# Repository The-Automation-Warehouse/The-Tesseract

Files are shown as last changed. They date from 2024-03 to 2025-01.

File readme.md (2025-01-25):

# The Tesseract

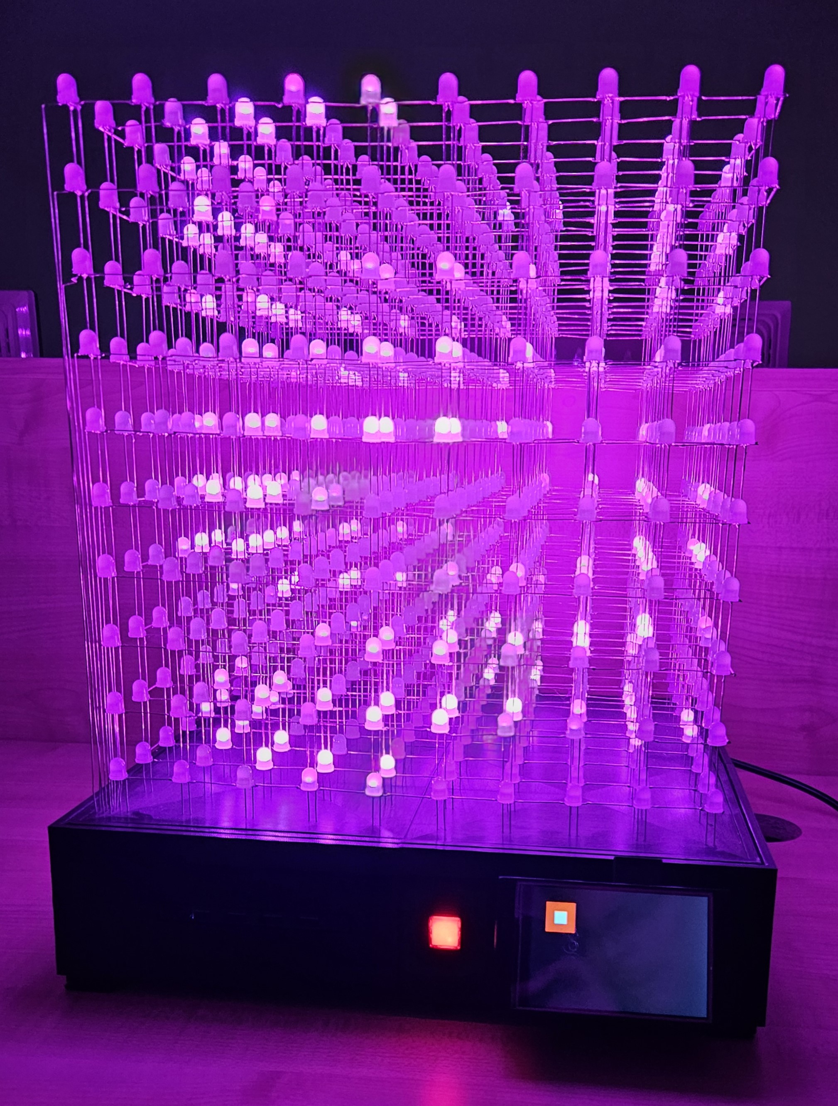
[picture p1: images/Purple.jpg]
Finished Project


## Introduction
This project is my DIY take on the popular RGB LED cube. I have always been fascinated by the mesmerizing patterns and animations that can be created with these cubes, so I used my school seminary work as an oporunity to build one myself and decided to turn in into a fully open-source project and guide for anyone who wants to build their own.

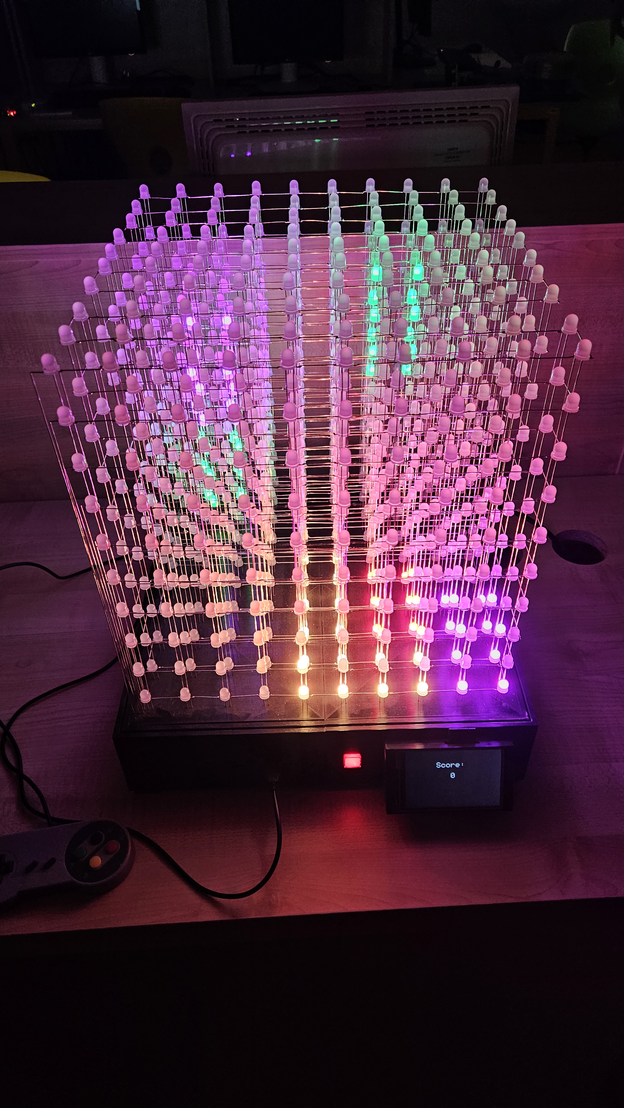
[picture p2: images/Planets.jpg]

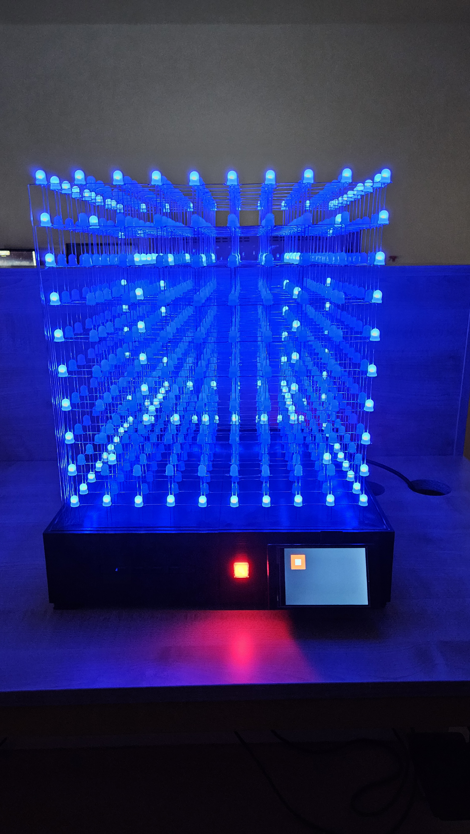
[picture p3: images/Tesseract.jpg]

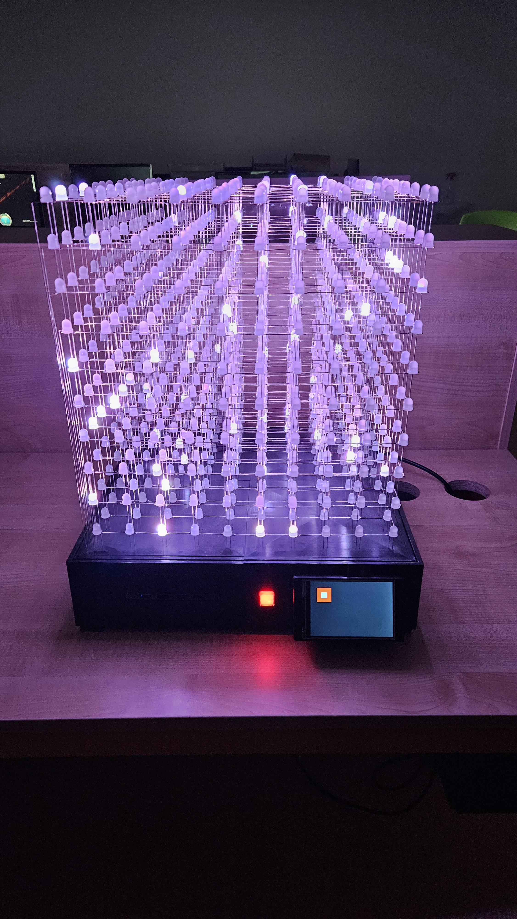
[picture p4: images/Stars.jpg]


## My Design
I decided to build a 10^3 cube, which means it has 1000 LEDs. I was thinking about making it bigger (12^3), but I wanted to keep the cost reasonable. In hindsight, if I had known how much time and effort it would take to build this cube, I would have gone for a much smaller one. But I am happy with the result, and I learned a lot in the process.<br>
I wanted the cube to be RGB and keep the electronics as simple as possible, so I used 8mm WS2812 LEDs, which are individually addressable and only need one data connection per LED stream.<br>
Most of the frame is make of custom PETG 3D printed parts, with some aluminum profiles and HDF board for structural support.<br>
For the brains of the cube, I used a teensy 4.1 microcontroller, which is a very powerful board that can handle the all of the LEDs and peripherals with ease.<br>
The user interface consists of a 4" TFT touch screen and a reset button (just in case).<br>
In the end the total cost was around 750 USD (720€), which is a lot, but I spent a lot of money on prototypes that ended up in the garbage, so I think it could be done for around 450 USD (430€) if you know what you are doing beforehand.

## Features
- 10 animations
- VU meter (audio reactive effect)
- TETRIS game via SNES controller
- Text rendering
- aprox. 300fps (effect dependent)

## How to build it

> [!TIP]
> - Refer to the CAD files and schematics, I tried to make them as detailed as possible.
> - Test the LEDs before soldering them, I know it is a pain (it took me 7 hours), but it is worth it.
> - Use the printed jigs (more on that later) to make the assembly easier.
> - **Turn off the power supply when working on the cube**, I know it is obvious, but I fried more than 30 LEDs after the cube was put together and resoldering them was a nightmare.
> - A good soldering iron helps a lot.

### Step 1: The LED structure :bulb:
The cube is split into walls and layers. Each wall has 100 LEDs, in 10 columns. Every wall is flipped 180º from the previous one. This results in a zig-zag pattern when viewed from the top. Every layer has its own data connection, to the MCU (more on that later). The walls are inserted into base plates and soldered together.

*Photo from the top here*
*Photo from the side here*

### Step 2: Preparing the wire
The LED connections are made with 0.8mm diameter silver copper wire. I got mine in 13m spools, and I ended up using 9 of them. The wire needs to be straightened and cut.<br>
Use a drill and a wise (or better a helper and pliers) to hold, pull and twist the wire (changing the direction every 8sec) until it is straight. Then use the cutting jig to cut the wire into 21mm pieces with wire cutters. For the collum power wires, cut 100 pieces of around 450mm (I used 500mm and it was too much, but I wanted to be safe).<br>

### Step 3: Soldering the LEDs
**Print the jigs**, soldering is practically impossible without them. 
There are 2 jigs (for the odd and even walls), each consisting of 4 parts that interlock like jig-saw puzzle. The 3d prints are not very heat resistant so I ended up melting them after 2-3 layers so I reprinted all of them 3 times to make the assembly easier.

Jig

Insert the LEDs into the jig in the right orientation, bend the outer legs to their respective sides and the inner two legs up.<br>
Cut the legs 2mm from the LED body and solder a connection wire to the outer legs between all of the LEDs. You should end up with 90 connections in total.<br>
Then solder the longer power wire to the inner legs, connecting all of the LEDs in the column. You should end up with 10 connections in total.<br>

Repeat this process 5 times for each jig, to end up with 10 walls.<br>

Wall
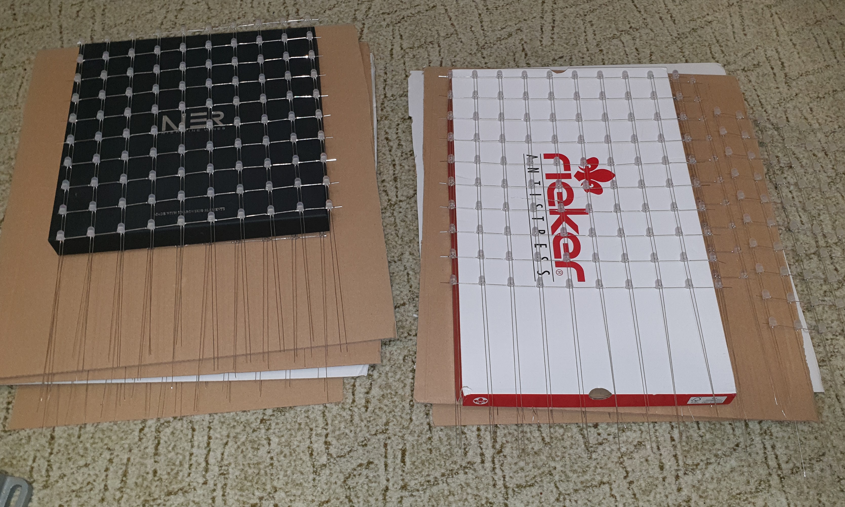
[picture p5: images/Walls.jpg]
Walls


*This looks quick and easy, but it took me around 3 months (working after school and on weekends) to finish all of the walls.*

### Step 4: Making the base plates
The base plates are made of two layers: a 3mm HDF board and a 3D printed grid. And they are split into 4 parts to make the manufacturing easier.

HDF base
Printed base

Cut 4 HDF boards to 175x175mm *drill holes for the LEDs*. The 4 plates are identical, but each is mirrored to the other. <br>
The drilling has to be precise, so I used a cheap 3018 CNC with a 1mm drill to make the HDF boards. You can find the excelon files in the CAD folder.<br>

Drilling

The 3D printed boards are just for looks and you can pain the HDF boards instead, but I think the 3D printed boards make the cube look more professional. I wasnt sure about the accuracy of the 3D printer for such small holes, so I made the holes Only on the bottom really small and drilled them on a drill press to the right size (0.8mm).<br>
I also picked a nice looking top infill pattern in the slicer to make the cube look better.

The front left plates need 10 holes in the front left corner for the data connections, I decided to make those by hand with a drill press, but you can also use the CNC for that.<br>

Printed base data

### Step 5: Connecting the walls to the base plates

This is definitely the most finicky part of the build. The walls have to be inserted into the base plates and soldered together. I used a very unstable rig to lower the walls into the base plates one by one (it ended ub collapsing and breaking a lot of solder joints, so I would recommend using something else).<br>

Rig

Insert the walls in an alternating pattern, checking the data flow. Start at the back with a wall that has the data connection going to the left, then insert a wall with the data connection going to the right, and so on. You should end up with a zig-zag pattern. Starting in the front left corner where the data input holes are.<br>
After the walls are inserted, the connections have to be soldered. Cut some more silver copper wire and solder the data connections to end of the walls.<br>

> [!TIP]
> - Print the brackets to hold the walls in place while soldering, it makes the process a lot easier. And reduces the risk of breaking the walls.

Cube structure

### Step 6: Wiring the base plates

You might have noticed that the polarity of the columns is a mess. This is to make the data connections easier and allow for more even current distribution.

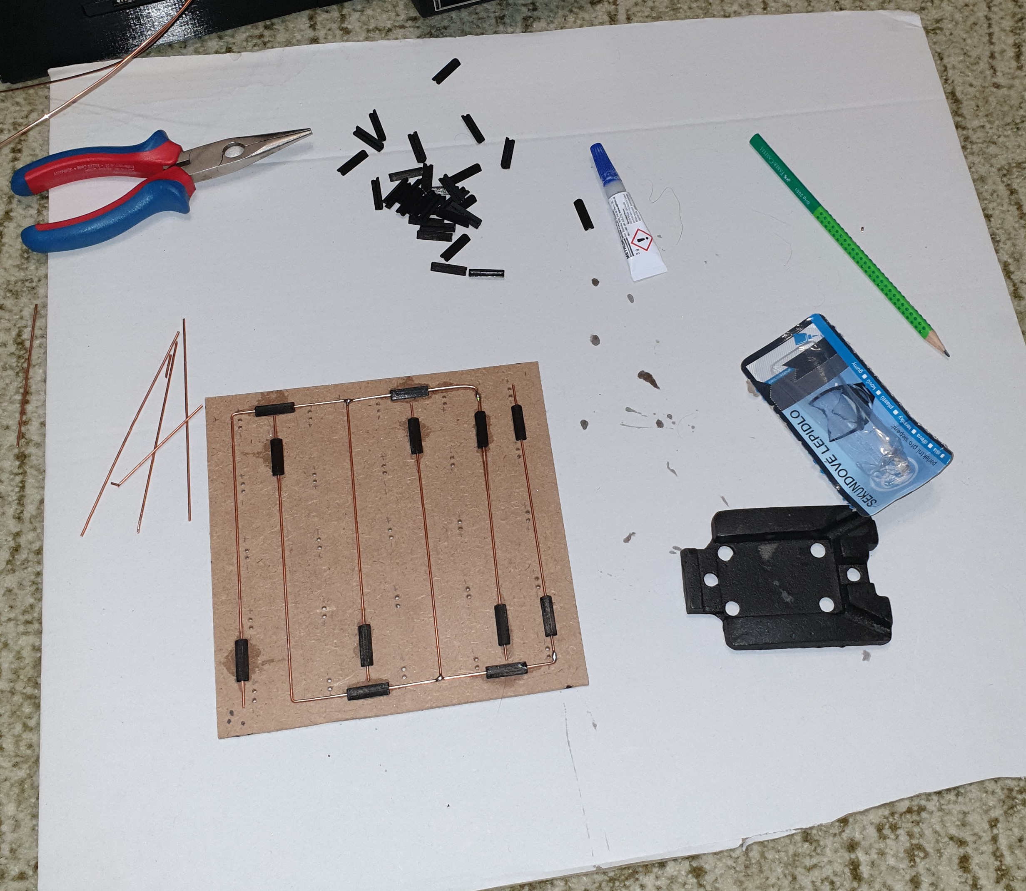
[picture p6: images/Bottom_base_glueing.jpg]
Bottom base glueing


I used 1.5mm2 wire and a lot of solder to make what I call the power planes. Each corner consists of two "power forks", one for +5V and one for GND. The silvered copper wire of each collum is directly soldered to the power planes.<br>

The thick wire is secured to the HDF with printed clamps and superglue (I would recommend using hotglue, because the superglue was very messy).<br>

> [!CAUTION]
> Pay attention to the polarity of the LEDs, flipping the power wires will burn the LEDs.

To connect the base plates to the PSUs, I used flexible 1.5mm2 wire and XT60 connectors soldered to the power planes. The other side of the XT60 connectors is soldered to the PSU wires.<br>
The data connections are made with thin ribbon cable, which is soldered to the 10 data connections on the front left corner of the base plates. The other side of the ribbon cable is connected to the motherboard with dupont connectors.<br>

Data cable
Bottom base wiring

### Step 7: Making the base frame

The frame is composed of 4 printed corners joined by 4 butterfly clips, 2 T aluminum profiles that hold the LED base plates and 5mm 350x350mm HDF board that everything is mounted on.

Corner Frame

Each corner has features and holes to mount specific peripherals (ex. the touch screen, the power inlet etc.).<br>
The remaining stuff is mounted on the HDF board with small wood screws - refer to the CAD files for the exact positions.<br>

Frame

### Step 8: The motherboard

The motherboard is a custom PCB that holds the Teensy 4.1, fusees, power distribution, battery clip, and all connectors for the peripherals.
I started by making a prototype on a breadboard and milling the next one on my CNC. The final version was made by JLCPCB, because it was too complex for me to make at home.

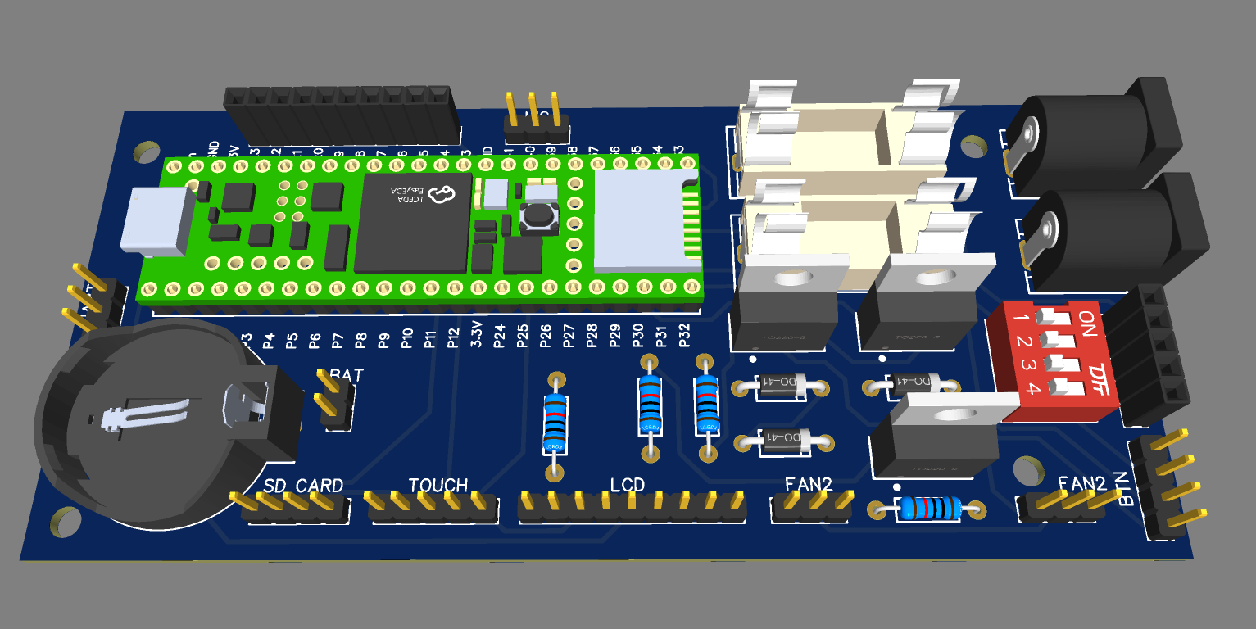
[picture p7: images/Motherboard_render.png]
Motherboard
 <br>

Breadboard
PCB prototype <br>

The board has DC jacks and fuses for 5V and 12V input (both required), a battery clip for the RTC, a port with DIP switches for a MAX9814 microphone breakout board, two MOSFET driven fan ports, breakout pins for the SPI touch screen with integrated SD card reader, and breakout pins for a reset button mounted in the front. There are also UART pins and analog MIC inputs, but I didn't use them in the final version.<br>
There are also dupont pins for the data connections to each layer of the cube.<br>
The most important part is the Teensy 4.1, which is the brains of the cube. It runs at 600MHz and has support for DMA which allows the cube to get up to 300fps in some animations.<br>

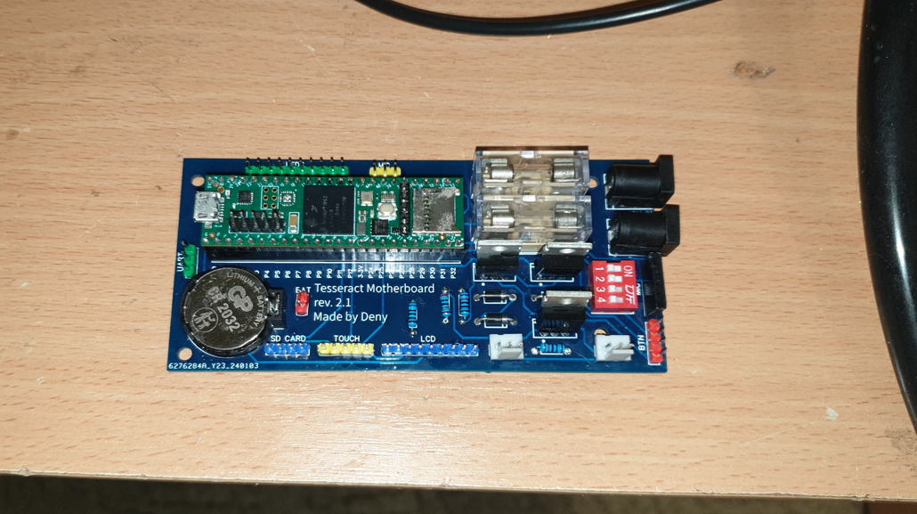
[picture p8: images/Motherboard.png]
Motherboard


### Step 9: Putting it all together :star:

If you have made it this far, congratulations:star2:! You are almost done. Now you just have to put everything without breaking it.<br>

Start by mounting all of the peripherals to the base frame.
- 2x 5V 40A PSU
- 12V 2A PSU
- The touch screen
- The reset button
- The USB hub
- 2x 12V fan
- C13 power inlet
- Back went cover
- Back IO (optional and not recommended)

Frame

Plug in all wires and place the LED structure on top of the base frame. Upload a test pattern and watch your cube come to life.

//video here

### Step 10: Software :computer:

The firmware is written in C++ and uses the FastLED library with the OctoWS2811 library to control the LEDs. The animations are stored in a separate file and are called by the main loop.<br>
The touch screen is controlled by the TFT_eSPI library and the touch screen library. The touch screen is mainly used to select animations. The SNES controller is connected via the USB hub and is used to play TETRIS.<br>

There is also a presentation mode, cycles through all of the animations.<br>

If you want to add your own animations, you can do so by adding a new function to the animations file and calling it in the main loop.

### Step 11: Enjoy you new RGB LED cube :tada:

I hope you enjoyed building this cube as much as I did. I learned a lot and I am very happy with the result. I hope you are too. If you have any questions or suggestions, feel free to post an issue or contact me directly.

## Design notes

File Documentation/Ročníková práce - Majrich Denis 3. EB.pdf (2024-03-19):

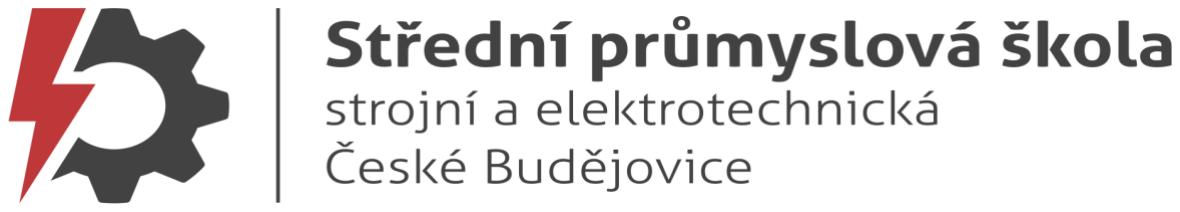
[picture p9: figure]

1

# The TESSERACT – Trojrozměrný LED displej ve tvaru krychle

## Ročníková práce

Jméno a příjmení: Denis Majrich | Třída: 3. EA

Vedoucí ročníkové práce: Ing. Lubomír Krejsa

Předmět: Mikroprocesorová technika

Školní rok: | 2023 – 2024

Střední průmyslová škola strojní a elektrotechnická České Budějovice, Dukelská 13

## Zadání ročníkové odborné práce

2

Zadání je vystaveno pro studenta :

Jména a příjmení: | Denis Majrich
Datum narození: | 2. 5. 2006
Třída: | 3. EA

Téma ročníkové práce:

### Trojrozměrný LED displej ve tvaru krychle

Požadované dílčí body práce:

1. Cílem ročníkové práce je vytvořit LED displej složený z jednoho tisíce jednotlivě

programovatelných LED diod uspořádaných do tvaru kostky o velikosti 10 x 10 x 10 diod.

2. Pro řízení displeje je nutné z důvodu vysokého výpočetního výkonu využít mikrokontroler

TEENSY 4.1.

3. K interakci s uživatelem bude sloužit dotykový TFT LCD displej s rozlišením 480 x 320 pixelů a

úhlopříčkou 4“.
4. Řídící software bude napsán v programovacím jazyce C++.

Cíl ročníkové odborné práce:

Prověřit znalosti studentů získané po dobu studia z odborných předmětů (elektronika, mikroprocesorová technika a IT) návrhem praktického zařízení.

Rozsah práce:

Práce bude obsahovat textovou část, která bude doplněná stručnou charakteristikou řešené problematiky, potřebnými náčrtky, schématy a tabulkami, vše v rozsahu minimálně 4 strany strojně psaného textu. Výkresová dokumentace bude obsahovat schéma zapojení, či jiná schémata potřebná k pochopení práce. Celá práce bude obsahovat obsah, přehled použitých značek s jejich názvem a jednotkami a zdroje. Práce se odevzdává ve dvou výtiscích – jedno pro vedoucího práce, druhý zůstává v archivu školy. Oba výtisky předá student vedoucímu práce.

3

Konzultace:

Student může po dobu zpracování ročníkové práce zkonzultovat výsledky doposud zpracované práce s vedoucím práce. Poslední konzultace je však nejpozději čtrnáct dní před odevzdáním.

Termín odevzdání práce: | 29.2.2024
Vedoucí práce: | Ing. Lubomír Krejsa | |
| | Podpis
Předseda předmětové komise: Ing. Lubomír Krejsa | |
| | Podpis
Kritéria hodnocení: | Hodnocení provádí vedoucí práce. Hodnotí se kvalita vypracování
dokumentace, správnost výpočtů a funkčnost navrženého zařízení.
Výsledné hodnocení: | výborný
| chvalitebný
| dobrý
| dostatečný
| nedostatečný

V Českých Budějovicích 03.10.2023

Převzetí zadání dlouhodobé ročníkové práce

Dne: | | | Podpis studenta

4

### Obsah

### 1. ÚVOD | 5

### 2. POSTUP PRÁCE | 6

2.1 | KONSTRUKCE | 6
2.1.1 | CAD | 6
2.1.2 | Podstava | 6
2.1.3 | Nosné desky | 7
2.1.4 | Uchycení displeje | 7
2.1.5 | LED diody | 8
2.2 | ŘÍDÍCÍ ELEKTRONIKA | 9
2.2.1 | Napájení | 9
2.2.2 | Řízení krychle a periferií | 9
2.2.3 | Systém Home Assistant | 10
2.3 | THE OMNITOUCH | 10
2.4 | SOFTWARE | 11
2.4.1 | Teensy 4.1 | 11
2.4.2 | Home Assistant | 12
2.4.3 | The Omnitouch | 12

### 3. ZÁVĚR | 14

SEZNAM ZKRATEK | 15
ZDROJE | 16
SEZNAM PŘÍLOH | 188

5

## 1. Úvod

Cílem mé ročníkové práce je vytvořit LED displej složený z jednoho tisíce jednotlivě programovatelných LED diod uspořádaných do tvaru kostky o velikosti 10 x 10 x 10 diod. Pro řízení displeje plánuji z důvodu nutnosti vysokého výpočetního výkonu využít mikrokontroler TEENSY 4.1. K interakci s uživatelem bude sloužit dotykový TFT LCD displej s rozlišením 480 x 320 pixelů a úhlopříčkou 4″.
Řídící software bude napsán v programovacím jazyce C++.
S použitím zvukového senzoru by animace na displeji mohly reagovat na okolní zvuky a hudbu.
Rád bych do projektu zakomponoval dva SNES ovladače s USB rozhraním, které umožní hrát na kostce různé hry pro jednoho nebo dva hráče jako např. PONG a do budoucna např. i TETRIS.
Dotykový displej bude obsahovat dvě různá menu, z nichž první bude určeno pro přehrávání animací nebo statických obrázků, druhé menu bude sloužit k volbě obtížnosti, počtu hráčů a zahájení her.

6

## 2. Postup práce

Veškeré tištěné díly jsou vytvořeny v programu Autodesk Fusion 360 a vytištěny na 3D tiskárně Prusa i3 Mk3S+ (viz příloha Modely) z černého materiálu PLA. Schémata zapojení a DPS jsou vytvořena v programu EasyEDA (viz příloha PCBs).

## 2.1 Konstrukce

### 2.1.1 CAD

Prvním krokem mé práce bylo sestavení požadavků na design mechanické konstrukce projektu.
Pro vytvoření modelu jsem využil software Autodesk Fusion 360, ve kterém jsem vymodeloval prototyp nosné konstrukce, u kterého jsem si určil rozteč jednotlivých diod a propočítal velikost finální krychle a její podstavy. Na základě toho jsem zjistil, kolik vznikne v podstavě prostoru na napájení, řídící elektroniku a kabeláž.

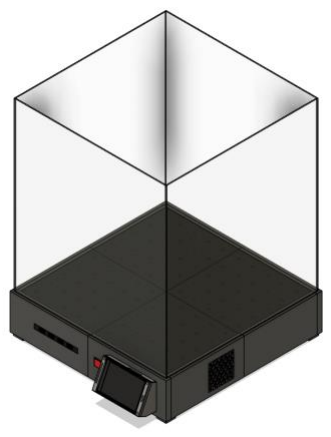
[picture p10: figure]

### 2.1.2 Podstava

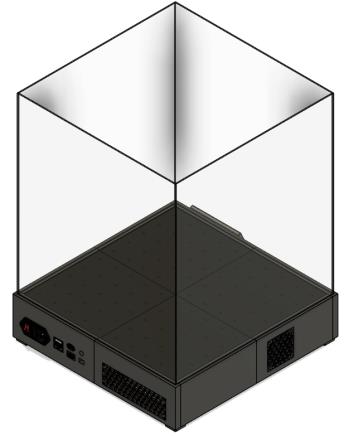
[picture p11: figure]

Výsledné rozměry podstavy jsou 375 x 375 mm, proto jsem se rozhodl rozdělit ji na čtyři části, které jsem poté spojil rybinovými ozuby, díky čemuž bylo možné je vytisknout na 3D tiskárně.

Spodní část podstavy tvoří sololitová deska natřená šedou barvou o tloušťce 4 mm z důvodu nutnosti udržení veškeré elektroniky.

Vrchní část je vyztužena dvěma na sebe kolmými hliníkovými profily ve tvaru T za účelem jejího osazení osmi nosnými deskami pro LED diody.

Do stran podstavy jsou vymodelovány otvory o různých rozměrech a tvarech, do kterých jsou zasazeny vstupní a výstupní periferie (např. chladící ventilátory, USB hub, hlavní vypínač, přívodní konektor nebo ethernet port).

Podstava má v každém rohu umístěnou nohu s pěnovým čtvercem z důvodu ochrany stolu.

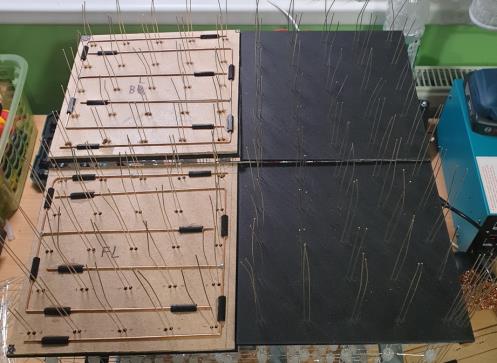
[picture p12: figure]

7

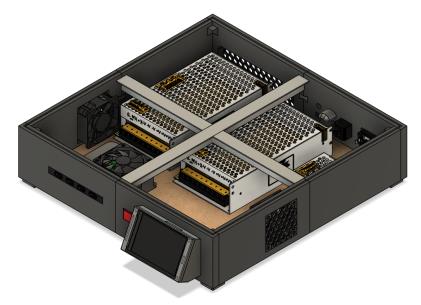
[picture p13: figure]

### 2.1.3 Nosné desky

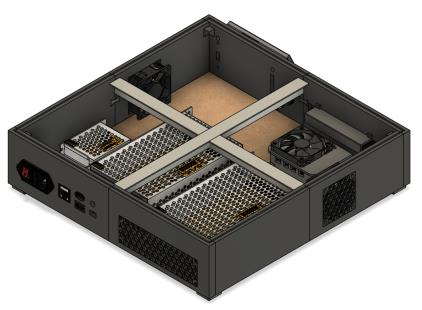
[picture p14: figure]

Konstrukce LED diod je osazena na osmi nosných deskách o rozměrech 175 x 175 x 3 mm s přesně určenými dírami pro lepší stabilitu.

Vrchní čtyři desky jsou vytištěny ze stejného materiálu jako podstava s koncentrickou vrchní výplní a slouží pouze pro zakrytí spodních čtyř desek ze 3 mm tlustého sololitu, na které jsou připevněné napájecí rozvody. Díry jsou vymodelované pouze do poloviny vrchních desek, kdy následně každá z nich představuje předlohu pro ruční vrtání spodní desky ze sololitu.

V levé přední desce se v levém předním rohu nachází deset těsně u sebe vyvrtaných děr pro protažení datových rozvodů jednotlivých vrstev krychle.

### 2.1.4 Uchycení displeje

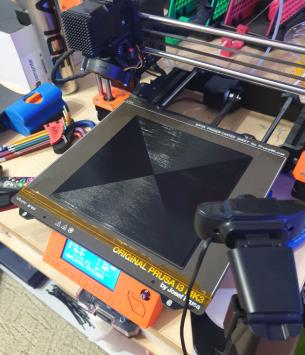
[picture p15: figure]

4″ TFT LCD displej je na pravé přední straně podstavy uchycen pod úhlem 25o tak, aby při pohledu na displej nebyly nikde patrné uchycovací šrouby a zároveň byl přístupný slot na SD kartu v horní části displeje.

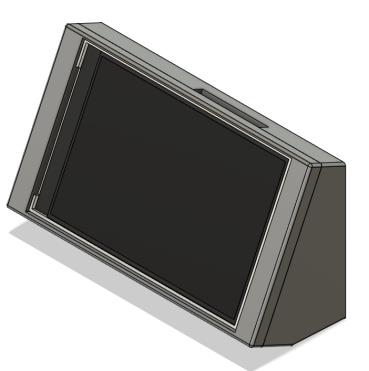
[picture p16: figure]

8

### 2.1.5 LED diody

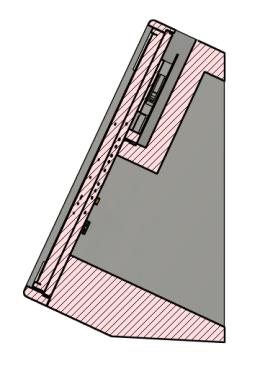
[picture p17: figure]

Krychle se skládá z jednoho tisíce adresovatelných RGB LED diod (pixelů) se zabudovaným ic WS28111, jenž umožňuje diody řídit 12 bity pro každou diodu; tedy celkem 2553 barev pro každý pixel.

Deset diod v každém ze sta sloupců je vertikálně připevněno na dvou měděných postříbřených drátech o průměru 0,8 mm.

Dráty zajišťují napájení každé diody v paralelním zapojení (viz bod 2.2.1).

Jednotlivé sloupce diod jsou spojeny v každé vrstvě stejným postříbřeným drátem. Stěny jsou mezi sebou propojovány drátem vždy střídavě ob jeden sloupec.

V levém předním rohu se nachází 10 datových vodičů, díky kterým lze řídit každou vrstvu nezávisle na ostatních devíti.

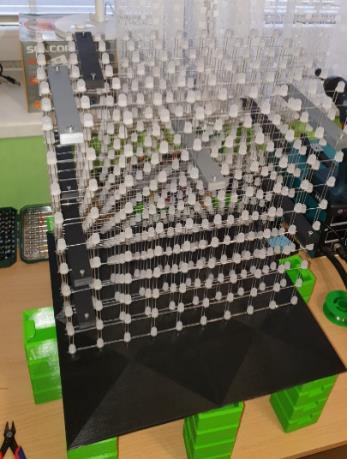
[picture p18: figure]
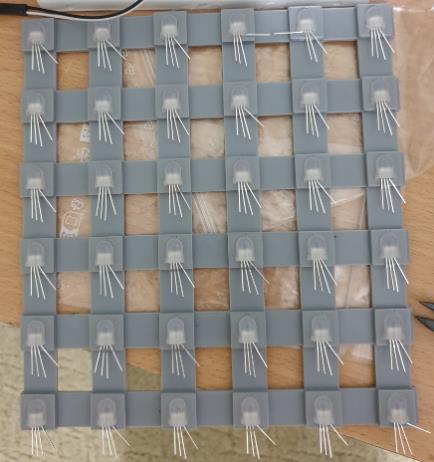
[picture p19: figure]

Pro usnadnění pájení jednotlivých vrstev jsem si vymodeloval a vytiskl plastové přípravky.

_____________________________

1
Stránky prodejce diod s dokumentací [online]. [cit. 12.2.2024]. Dostupné z: https://www.aliexpress.com/item/4000720415203.html?spm=a2g0o.order_list.order_list_main.9.76 c81802TY4kjk (https://www.aliexpress.com/item/4000720415203.html)

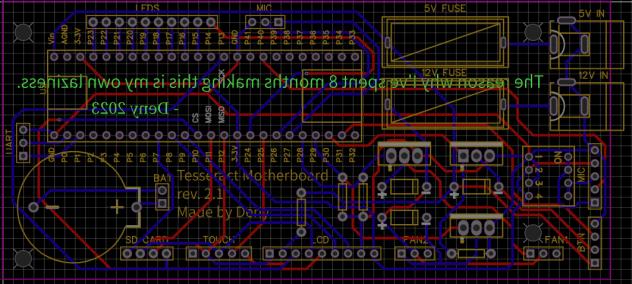
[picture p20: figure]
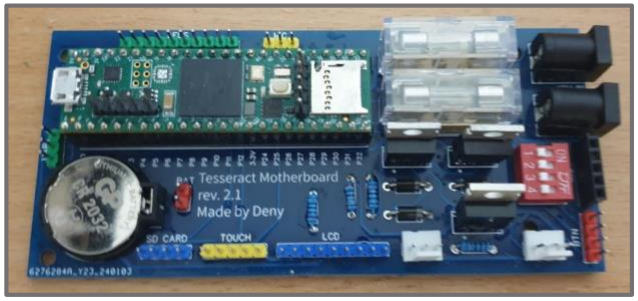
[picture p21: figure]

9

## 2.2 Řídící elektronika

### 2.2.1 Napájení

Napájení celého projektu zajišťují tři zdroje, z toho dva s nominálním napětím 5V a maximálním proudem 40A a třetí s nominálním napětím 12V a maximálním proudem 2A.

5V zdroje slouží k napájení diod a veškeré řídící elektroniky. 12V zdroj je určen pro dva chladící ventilátory umístěné po bocích podstavy.

Distribuce proudu LED diod je realizována paralelním spojením všech pixelů na spodní části nosných desek. Jednotlivé kvadranty jsou se sloupci spojené měděným drátem o průřezu 1,5 mm a k příslušnému napájecímu zdroji jsou připojeny lankovým vodičem o průřezu 2,5 mm. Toto spojení minimalizuje úbytek napětí mezi diodami.

### 2.2.2 Řízení krychle a periferií

Pro snadnější zapojení řídící elektroniky jsem se rozhodl navrhnout vlastní DPS, která umožní snadné propojení řídícího mikrokontroleru, vrstev krychle a veškerých periferií.

První verzi DPS jsem vyrobil pomocí CNC frézy, po zjištění a opravě veškerých nedostatků jsem finální verzi DPS objednal od externího dodavatele.

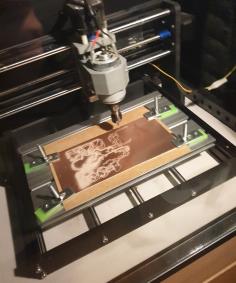
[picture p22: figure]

Jako hlavní mikrokontroler jsem zvolil TEENSY 4.1, a to např. kvůli jeho vysoké pracovní frekvenci až 1,08 GHz, paměti Flash o velikosti 8 MB, paměti RAM o velikosti 1024 kB, 55 vstupně/výstupním pinům, matematickému koprocesoru a užitečné funkci DMA, která umožňuje řídit všechny vrstvy krychle najednou a dosáhnout tak obnovovací frekvence ca 320 fps.

Mikrokontroler dále řídí také přes sběrnici SPI:

10

4″ TFT LCD displej

dotykovou vrstvu displeje

slot na SD kartu

Funkce USB host zajišťuje komunikaci mezi zařízeními USB připojenými přes hub v přední části podstavy a jeho primární využití je pro dva SNES ovladače určené pro hraní her, např. TETRIS nebo PONG (prozatím pro jednoho hráče; v budoucnu plánuji přidat režim pro více hráčů).

Pomocí dvou unipolárních tranzistorů typu MOS s N-kanálem jsou ovládány dva chladící ventilátory s možností regulace výkonu prostřednictvím PWM.

Tlačítko se zabudovaným podsvícením se stejnou regulací jako ventilátory slouží pro nouzové vypnutí a reset mikrokontroleru.

Některé světelné efekty mohou reagovat na okolní zvuk (hudbu) ze dvou zdrojů:

mikrofon MAX9814 se zabudovaným zesilovačem s nastavitelným zesílením pomocí DIP přepínačů na DPS

dvoukanálový audiojack s RC filtrem připojený do Raspberry Pi 4 (viz bod 2.2.3)

Mikrokontroler je propojen s Raspberry Pi 4 (viz bod 2.2.3) přes sériovou linku typu UART.

DPS obsahuje slot na baterii CR2032, která slouží k záložnímu napájení interních hodin reálného času uvnitř mikrokontroleru v případě výpadku hlavního zdroje.

### 2.2.3 Systém Home Assistant

V podstavě krychle je umístěn jednodeskový počítač Raspberry Pi 4B určený pro běh systému Home Assistant na ovládání chytré domácnosti. Tento systém umožňuje propojení zařízení pro chytrou domácnost od různých výrobců a jejich následnou integraci do vlastních programů, skriptů a automatizací.

Systém komunikuje s TEENSY 4.1 pomocí skriptu v jazyce Python přes protokol UART, přičemž posílá data o entitách v systému a příkazy z ovladače The Omnitouch (viz bod 2.3). Tím je zajištěna interakce mezi zařízeními chytré domácnosti (např. světly, zásuvkami, počítači, senzory atd.) a krychlí TESSERACT.

Do projektu plánuji zahrnout vizualizaci hlasového asistenta na krychli.

## 2.3 The Omnitouch

Pro názornou ukázku univerzálnosti platformy Home Assistent jsem vytvořil zařízení, které lze přes tuto platformu s krychlí propojit, a tím je The Omnitouch.

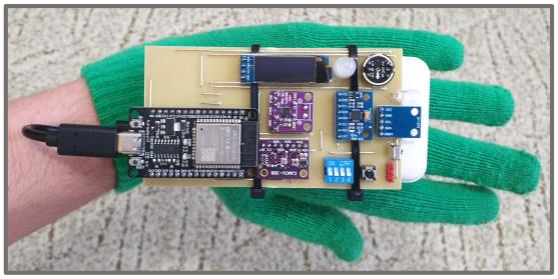
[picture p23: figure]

11

Jedná se o „rukavici“ s osmi senzory a čtyřmi přepínači, tlačítkem, RGB diodou, OLED displejem o rozlišení 128 x 32 pixelů a připojením prostřednictvím wifi skrze platformu a protokol ESPHome.

Základem je mnou navržená a vyrobená DPS s vývojovou deskou ESP32-WROOM-32D. Napájení přes konektor USB-C na vývojové desce zajišťuje powerbanka umístěná pod DPS.

Jednotlivé senzory The Omnitouch:

tříosý magnetometr a kompas HMC5883L

šestiosý akcelerometr MPU6050

detektor teploty a tlaku BMP388

Hallův senzor magnetického pole

mikrofon INNP441

IR přijímač VS1838B

Primární využití zařízení je při prezentaci krychle pro bezdrátové přepínání mezi efekty, vizualizaci teploty nebo magnetického pole.

I2S mikrofon slouží pro možnost hlasového ovládání chytré domácnosti.

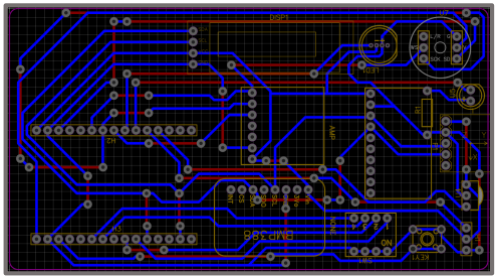
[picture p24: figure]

## 2.4 Software

### 2.4.1 Teensy 4.1

Řídící software pro mikrokontroler Teensy 4.1 je napsán v jazyce C++ pomocí deseti volně dostupných knihoven. Skládá se z hlavního skriptu main.cpp a pomocných souborů typu .h pro jednotlivé efekty a podřízené funkce.

Hlavní funkcí pro řízení diod je funkce void setLed(int x, int y, int z, CRGB color), jež je určena k nastavení jednoho pixelu krychle na určitou barvu. Jejím vstupem jsou kartézské souřadnice [x, y, z] následně převedené na index diody ve virtuálním poli pomocí funkce int getLedIndex(int x, int y, int z), kam funkce ukládá barevná data příslušné diody.

Celý kód mikrokontroleru je složen z přibližně 5000 řádek rozdělených do 22 souborů.

Jednotlivé soubory obsahují proměnné a funkce pro řízení částí a činností krychle, např.:

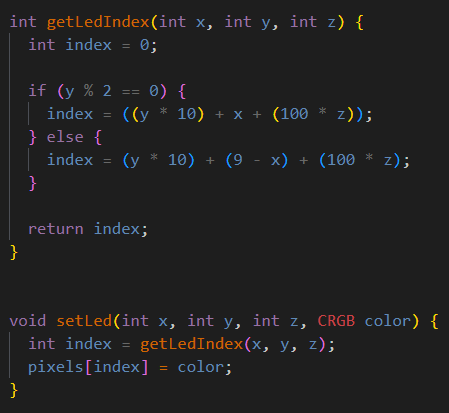
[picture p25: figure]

12

soubor pro řízení a zpracování dat SNES ovladačů

soubor pro virtuální mikrokontroler k řízení všech 10 vrstev krychle najednou pomocí DMA

soubor pro hraní hry TETRIS

soubor pro zpracování a vykreslování textu

soubor pro zpracování zvuku (hudby) a jeho převedení na frekvenční spektra za použití Fourierovy transformace a následné zobrazení jednotlivých pásem na krychli

pomocný soubor s funkcemi pro řízení SD karty, ladícími funkcemi nebo např. funkcí pro vykreslování virtuálních desetinných pixelů

soubor pro vykreslování hlavního menu, různých podmenu na LCD displeji, zpracování a filtraci dat z dotykové vrstvy

14 souborů týkajících se jednotlivých efektů LED diod

### 2.4.2 Home Assistant

Většina konfigurace systému Home Assistent probíhá ve vizuálním prostředí.

Pro pokročilejší funkce lze využít programovacího jazyka YAML. Dále lze pomocí rozšíření pyskript vytvářet a spouštět v pozadí systému podprogramy v jazyce Python, např. pro sériovou komunikaci s krychlí prostřednitvím UART.

### 2.4.3 The Omnitouch

Software pro The Omnitouch je vytvořen pomocí platformy ESPHome v programovacím jazyce YAML. Tato platforma umožňuje snadné propojení několika periferií skrze jednoduchou deklaraci jejich typů a atributů.

Pokročilejší funkce lze naprogramovat pomocí funkcí typu lambda.

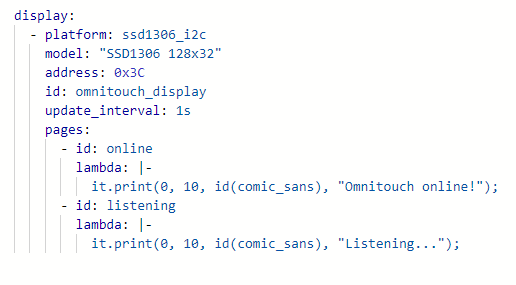
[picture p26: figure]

13

V přiložené složce Foto a video se nachází videa a fotografie práce.

14

## 3. Závěr

V souladu s cílem práce se podařilo vytvořit LED krychli s 1000 pixely s deseti funkčními efekty, z toho dvěma reagujícími na hudbu.

Základním efektem je duha, při které je vyplněna celá krychle jednou barvou, jež se vždy
v čase mění. Mezi další efekty patří např. vykreslování textu či hodin, náhodné hvězdy v bílé nebo barevné variantě, planety obíhající kolem středu nebo dvojitá spirála otáčející se kolem vertikální osy.

Na krychli je možné hrát známou hru TETRIS ve 3D pro jednoho hráče pomocí USB SNES ovladače (do budoucna plánuji rozšíření pro více hráčů).

Celá krychle obsahuje zabudovaný funkční systém Home Assistant pro řízení a automatizaci chytré domácnosti.

Efekty na krychli je možné např. pro účely prezentace přepínat pomocí chytré rukavice The Omnitouch, prostřednictvím níž lze také hlasově řídit chytrou domácnost.

Nejsložitější částí práce byl návrh a následná stavba konstrukce všech diod zejména z důvodu rozměrů krychle, a tudíž nestability tenkých měděných drátů. Často docházelo k přetržení pájených spojů nebo dokonce zničení některých diod.

Odhad celkových finančních nákladů na vytvoření LED krychle této ročníkové práce se pohybuje kolem 17 tis. Kč. Práce byla zhotovena v období 8 měsíců, největší časový prostor zabral CAD a pájení diod.

Hlavním přínosem zpracování projektu pro mne bylo zlepšení dovednosti pájení, programování v různých jazycích, modelování v CADu a návrh elektronických schémat a DPS.

Rozhodl jsem se celý projekt vč. softwaru, CADU ve formátu .step, fotografií a dokumentace zveřejnit na platformě GitHub pod licencí typu MIT (https://github.com/The-Automation-Warehouse/The-Tesseract.git) (https://github.com/The-Automation-Warehouse/The-Tesseract.git)

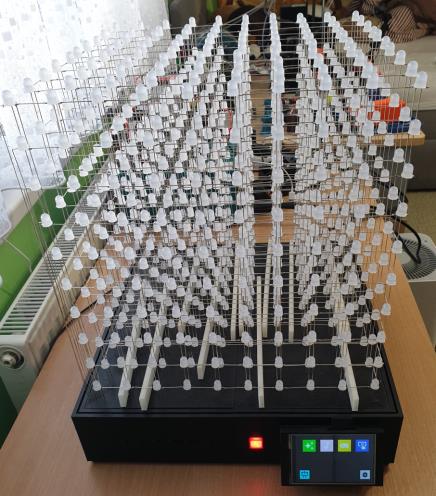
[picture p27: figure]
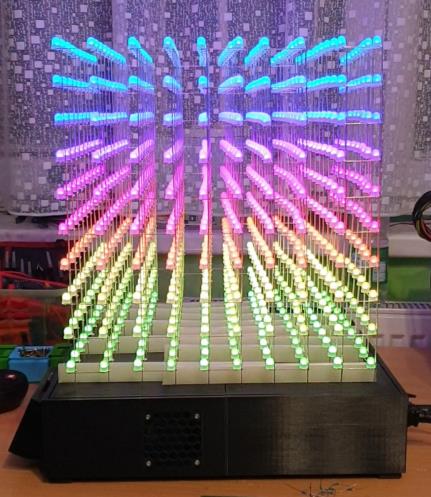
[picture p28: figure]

15

## Seznam Zkratek

TFT | Thin-film transistor (tenkovrstvé tranzistory)
LCD | Liquid crystal display (Displej z tekutých krystalů)
PLA | Polylactic acid (materiál pro 3D tisk)
CAD | Computed aided design (počítačem podporované projektování)
ic | Integrated circuit (zabudovaný čip)
DPS (PCB) | Printed circuit board (deska plošného spoje)
CNC | Computer numeric control (počítačové numerické řízení)
RAM | Random access memory (paměť s náhodným přístupem)
DMA | Direct memory access (přímý přístup k paměti)
fps | Frames per second (snímky za vteřinu)
SNES | Super nintendo entertainment system (herní platforma)
MOS | Metal oxide semiconductor (tranzistor řízený polem)
PWM | Pulse width modulation (pulzně šířková modulace)
DIP | Dual in-line package (pouzdro integrovaných obvodů)
UART | Universal asynchronous receiver-transmitter (typ počítačové sběrnice)
OLED | Organic light-emitting diode (technologie displeje)
I2S | Inter-IC Sound (typ počítačové sběrnice)

16

## Zdroje

### Internetové zdroje

1.Web prodejce LED diod s dokumentací [online]. Aliexpress. (2024). [cit. 12.2.2024]. Dostupné z:
https://www.aliexpress.com/item/4000720415203.html?spm=a2g0o.order_list.order_list_mai n.9.76c81802TY4kjk (https://www.aliexpress.com/item/4000720415203.html)
2. Web výrobce mikrokontroleru Teensy 4.1 s dokumentací [online]. 2024 PJRC. [cit. 12.12.2024]. Dostupné z: https://www.pjrc.com/store/teensy41.html
3. Web výrobce jednodeskového počítače Raspberry Pi 4B s dokumentací [online]. 2024 Raspberry Pi. [cit. 12.12.2024]. Dostupné z: https://www.raspberrypi.com/products/raspberrypi-4-model-b/ (https://www.raspberrypi.com/products/raspberry-pi-4-model-b/)
4. 3D model Raspberry Pi 4B [online]. 2024 Stratasys Inc. Grabcad.com. [cit. 12.12.2024]. Dostupné z: https://grabcad.com/library/raspberry-pi-4-model-b-5
5. 3D model Chladícího ventilátoru [online]. 2024 Stratasys Inc. Grabcad.com. [cit. 12.12.2024]. Dostupné z: https://grabcad.com/library/60-x-60-x-25-exhaust-fan
6. 3D model 12V zdroje [online]. 2024 Stratasys Inc. Grabcad.com. [cit. 12.12.2024]. Dostupné z: https://grabcad.com/library/fuente-conmutada-12v-2a-12v-3a-12v-5a-12v-10a-12v-30a-12v-50a-1 (https://grabcad.com/library/fuente-conmutada-12v-2a-12v-3a-12v-5a-12v-10a-12v-30a-12v-50a-1)
7. 3D model 5V zdroje [online]. 2024 Stratasys Inc. Grabcad.com. [cit. 12.12.2024]. Dostupné z: https://grabcad.com/library/fuente-conmutada-5v-3a-5v-10a-5v-40a-1
8. 3D model napájecího konektoru [online]. 2024 Stratasys Inc. Grabcad.com. [cit. 12.12.2024]. Dostupné z: https://grabcad.com/library/ac-power-socket-3-pin-250v-10a-ac-17-iec3-c14-1 (https://grabcad.com/library/ac-power-socket-3-pin-250v-10a-ac-17-iec3-c14-1)
9. 3D model konektoru RJ45 [online]. 2024 Stratasys Inc. Grabcad.com. [cit. 12.12.2024]. Dostupné z: https://grabcad.com/library/rj45-panel-mount-1
10. 3D model mikrokontroleru Teensy 4.1 [online]. 2024 Stratasys Inc. Grabcad.com. [cit. 12.12.2024]. Dostupné z: https://grabcad.com/library/teensy-4-1-3
11. 3D model vypínače [online]. 2024 Dassault Systèmes. 3dcontentcentral.com. [cit. 12.12.2024]. Dostupné z: https://www.3dcontentcentral.com/download-model.aspx?catalogid=171&id=345299 (https://www.3dcontentcentral.com/download-model.aspx?catalogid=171&id=345299)
12. 3D model 5V ventilátoru [online]. 2024 CUI Devices. Cuidevices.com. [cit. 12.12.2024]. Dostupné z: https://www.cuidevices.com/product/resource/3dmodel/cfm-6010v-130-205-20
13. 3D model USB portu [online]. 2024 CUI Devices. Cuidevices.com. [cit. 12.12.2024]. Dostupné z: https://www.cuidevices.com/product/resource/3dmodel/uj3-ah-4-th

17

Počítačové programy

1. Autodesk Inc, Fusion 360 [software]. 24. 9. 2013. Dostupné z: https://www.autodesk.cz/products/fusion-360.
2. Prusa Research a.s., Prusaslicer 2.5 [software]. 19. 8. 2022. Dostupné z: https://www.prusa3d.com/cs/stranka/prusaslicer_424/.
3. Microsoft corp, Visual Studio Code [software]. 29. 4. 2015. Dostupné z: https://code.visualstudio.com/.
4. PlatformIO Labs, PlatfromIO [software]. 6. 1. 2015 Dostupné z: https://platformio.org/.
5. LCSC, EasyEDA [software]. 14. 9. 2021. Dostupné z: https://easyeda.com/.
6. Nabu Casa, Home Assistant [software]. 19. 10. 2017 Dostupné z: https://www.home-assistant.io/. (https://www.home-assistant.io/)
7. Nabu Casa, ESPHome [software]. 7. 12. 2023 Dostupné z: https://esphome.io/index.html

18

## Seznam příloh

Příloha I. – elektronická složka Foto a video (videa různých efektů; videa o tisku dílů; video o zkoušce diod; 83 fotografií)

Příloha II. – elektronická složka Code (kód krychle – The Tesseract; kód ovladače Omnitouch – The Omnitouch)

Příloha III. – elektronická složka PCB (elektronická schémata v formátu .png a .json; soubory DPS ve formátu .png a gerber)

Příloha IV. – elektronická složka Modely (vlastní modely ve formátech .3mf, .step a .f3d)

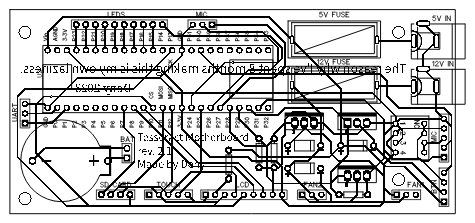
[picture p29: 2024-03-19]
PCB/Tesseract_Motherboard_PCB.png

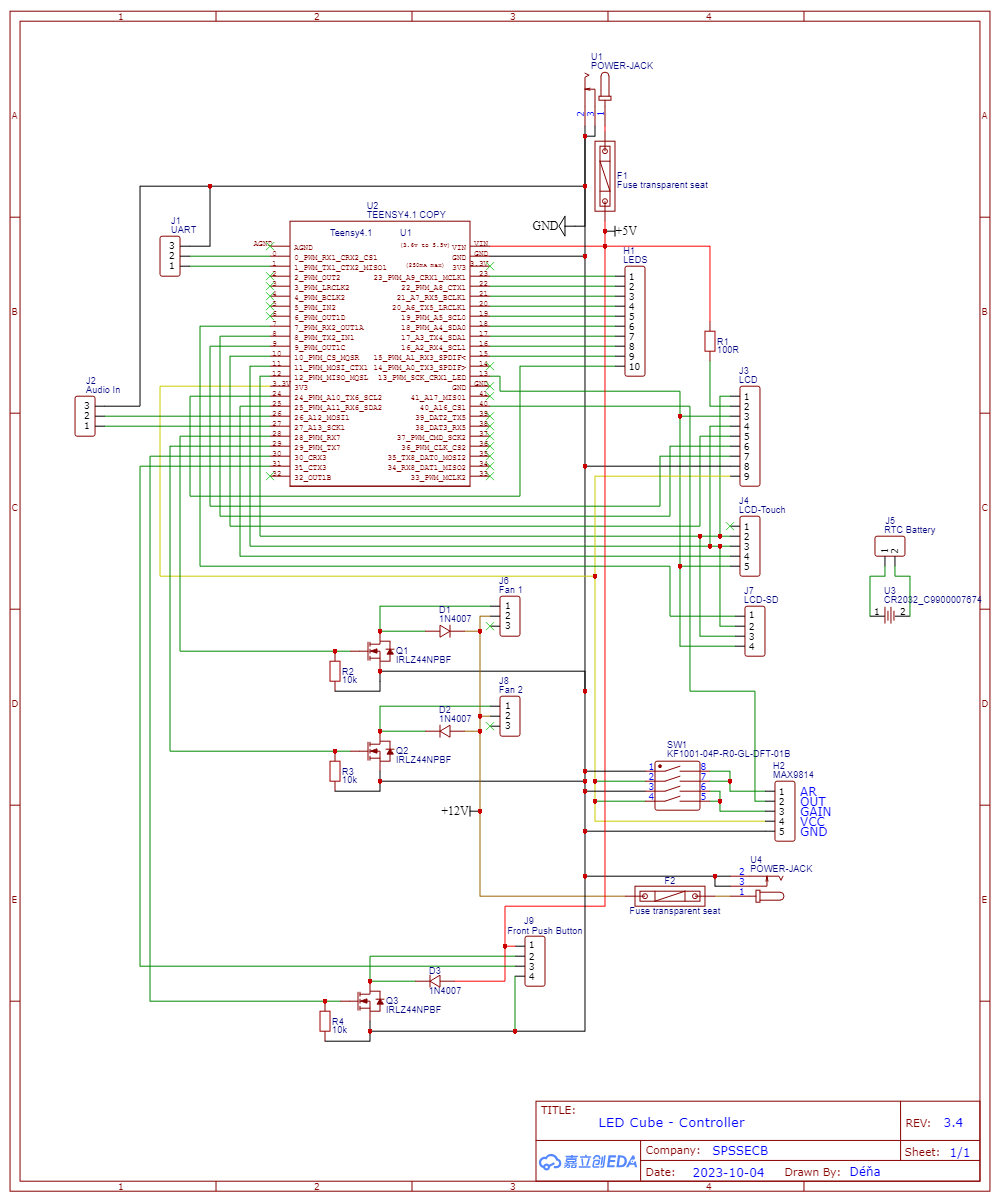
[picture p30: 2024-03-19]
PCB/Tesseract_Motherboard.png

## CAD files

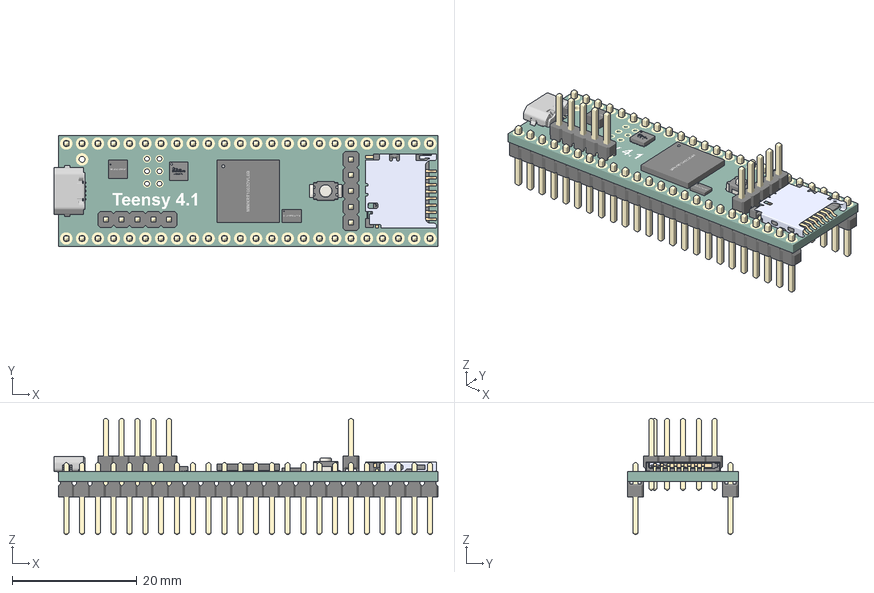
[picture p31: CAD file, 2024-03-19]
CAD/3mf/Teensy 4.1.3mf
61.7 x 17.8 x 18.7 mm

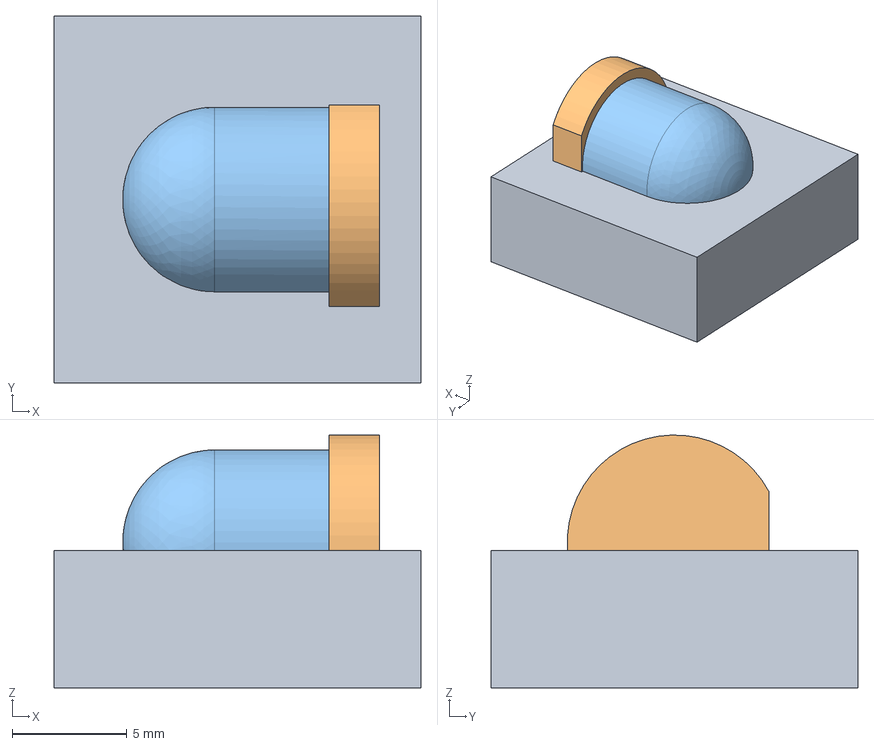
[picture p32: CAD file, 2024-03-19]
CAD/Step/1x1 Jig.step
16.0 x 16.0 x 11.0 mm

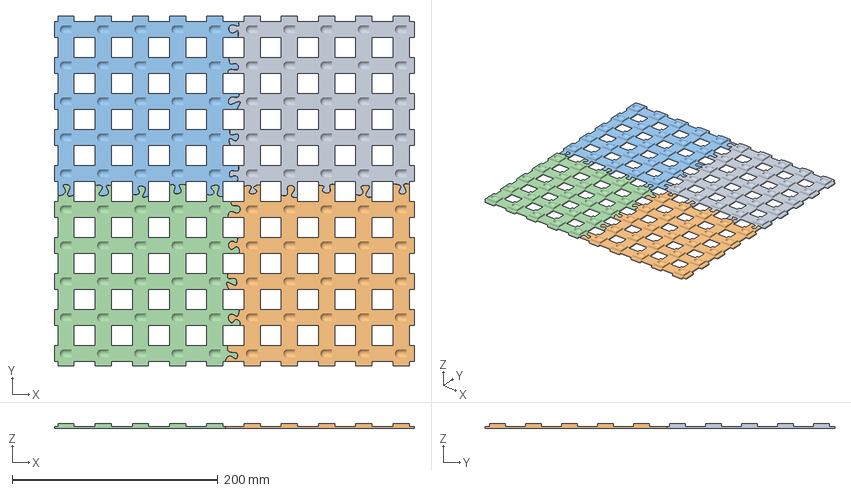
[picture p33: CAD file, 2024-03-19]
CAD/3mf/10x10 Jig.3mf
350.0 x 340.0 x 5.30 mm

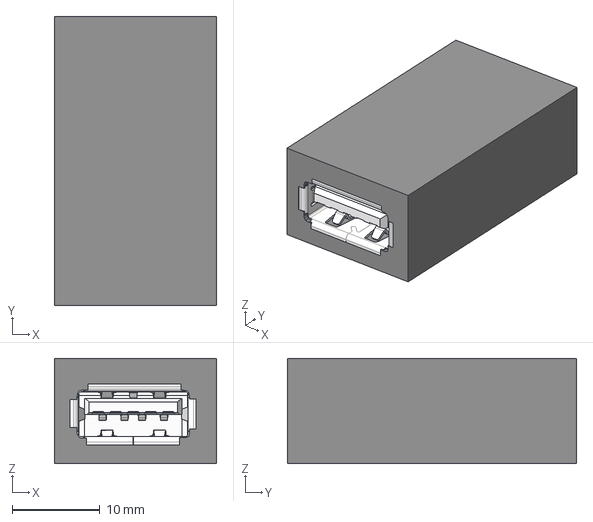
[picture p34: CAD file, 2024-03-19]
CAD/Step/Generic USB Extension Female Port.step
18.5 x 33.0 x 12.0 mm

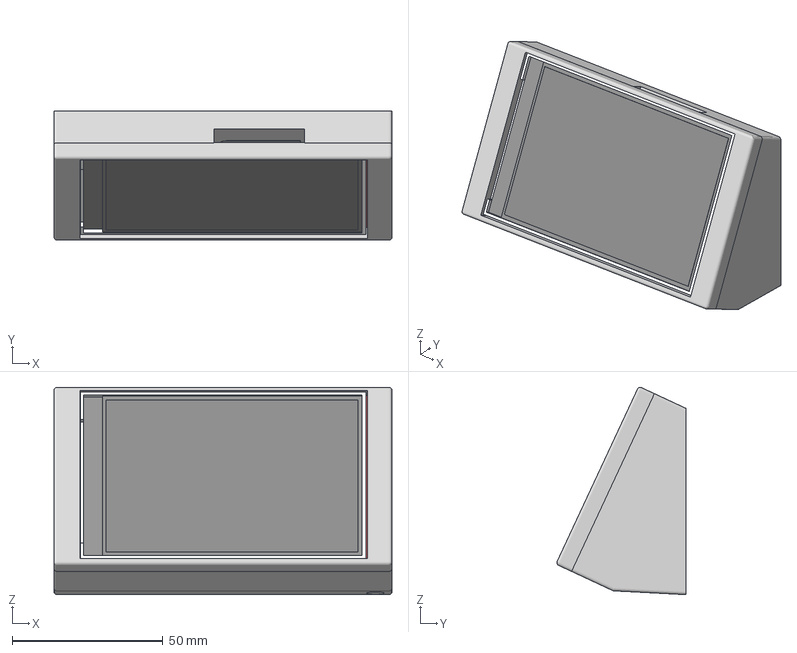
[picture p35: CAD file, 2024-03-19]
CAD/3mf/4 inch TFT LCD Mount.3mf
112.0 x 42.9 x 68.7 mm

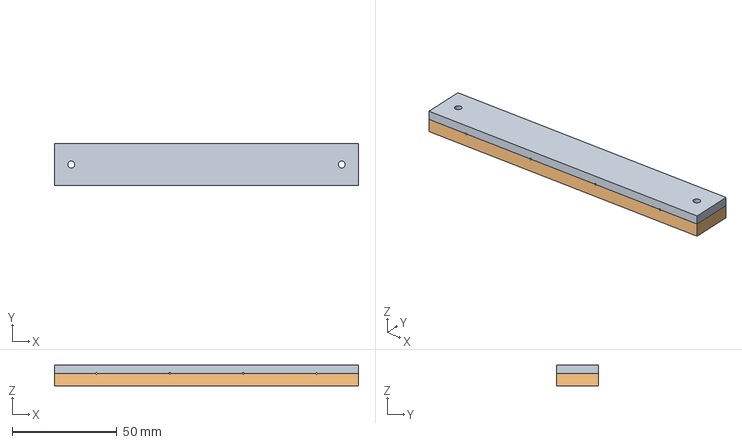
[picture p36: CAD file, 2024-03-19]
CAD/Step/Alignment Clip.step
145.0 x 20.0 x 10.0 mm

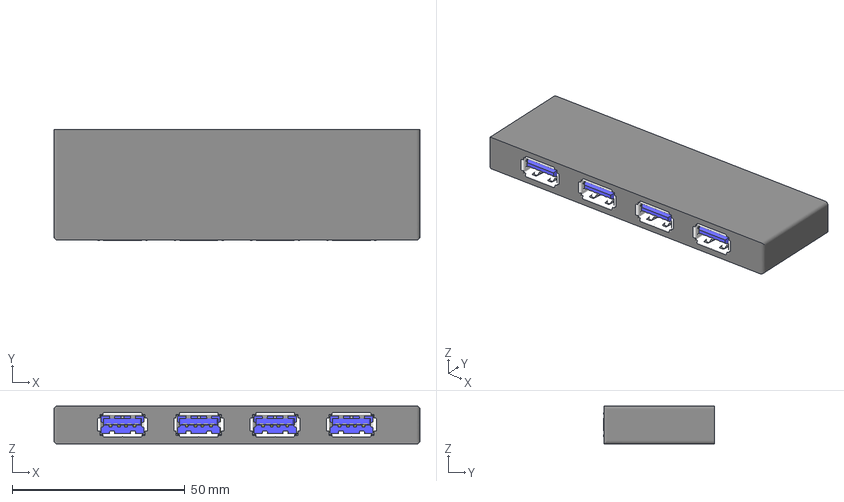
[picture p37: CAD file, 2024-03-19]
CAD/3mf/Axagon HUE-C1A USB Hub.3mf
106.0 x 32.1 x 11.0 mm

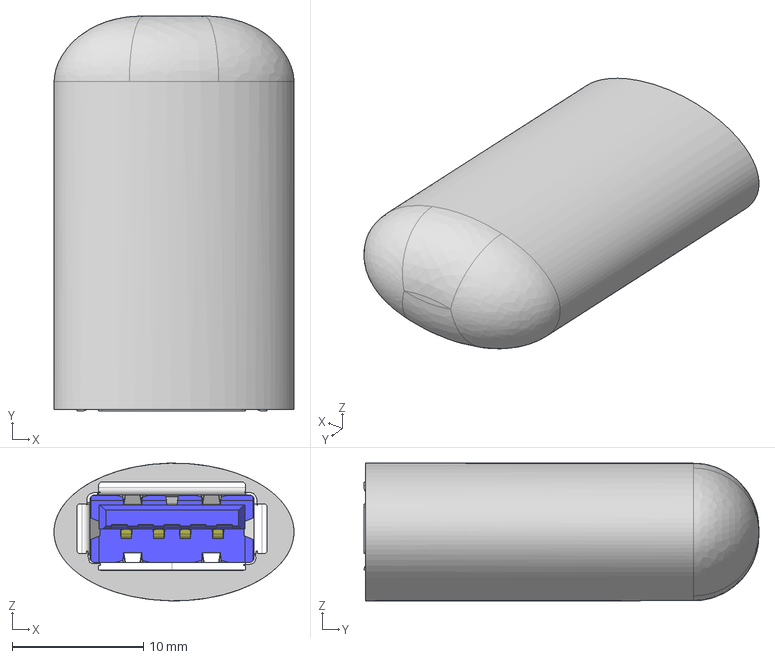
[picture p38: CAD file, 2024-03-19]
CAD/Step/Vention USB Extension Female Port.step
18.3 x 30.1 x 10.5 mm

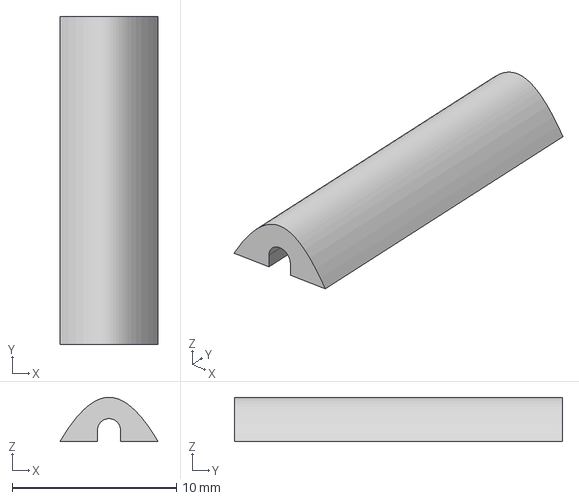
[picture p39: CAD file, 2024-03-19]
CAD/Step/Cable Clamp.step
6.00 x 20.0 x 2.70 mm

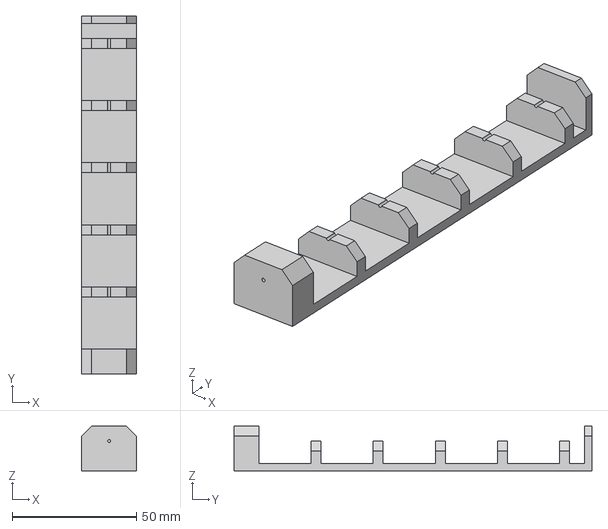
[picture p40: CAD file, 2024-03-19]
CAD/Step/Led Connector Wire Jig.step
22.0 x 144.0 x 18.0 mm

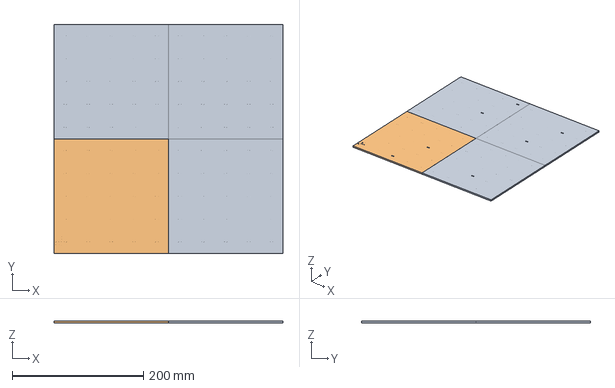
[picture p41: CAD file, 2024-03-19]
CAD/Step/Base Plate.step
349.6 x 349.6 x 3.00 mm

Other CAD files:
CAD/3mf/1x1 Jig.3mf
CAD/3mf/Alignment Clip.3mf
CAD/3mf/Base Plate.3mf
CAD/3mf/Cable Clamp.3mf
CAD/3mf/Generic USB Extension Female Port.3mf
CAD/3mf/Led Connector Wire Jig.3mf
CAD/3mf/Vention USB Extension Female Port.3mf
CAD/F3d/1x1 Jig.f3d
CAD/F3d/Alignment Clip.f3d
CAD/F3d/Base Plate.f3d
CAD/F3d/Cable Clamp.f3d
CAD/F3d/Generic USB Extension Female Port.f3d
CAD/F3d/Led Connector Wire Jig.f3d
CAD/F3d/Vention USB Extension Female Port.f3d

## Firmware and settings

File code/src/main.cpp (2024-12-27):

//include all the required libraries
#include <Arduino.h>
#include <SPI.h>
#include <InternalTemperature.h>
#include <TFT_eSPI.h>
#include <OctoWS2811.h>
#define USE_OCTOWS2811
#include <FastLED.h>
#define FastLED_INTERNAL
#include <SD.h>
#include <TimeLib.h>
#include <USBHost_t36.h>
#include <Wire.h>
#include "ArduinoJson.h"
#include "Entropy.h"

#include "tesseractFunctions.h"
#include "joystick.h"
#include "CTeensy4Controller.h"
#include "menu.h"

#include "effects/effects.h"

#include "presentation.h"




#define SD_CS 7
const int LEFT_FAN = 28;
const int RIGHT_FAN = 29;
#define BUTTON 31
#define BUTTON_LIGHT 33
int channel1 = 26;
int channel2 = 27;
int mic = 40;

#define initDelay 300
int i = 0;
String uint32ToBinary(uint32_t value);
float temp;
void setFanSpeed(int temp);
void startEffect(int effect, int effectType);

//add a function to reset the teensy on the press of a button using an interrupt
void resetTeensy() {  SCB_AIRCR = 0x05FA0004; digitalWrite(BUTTON_LIGHT, LOW); }


// define all objects and variables for the LCD
TFT_eSPI tft = TFT_eSPI();
int nextMenu = 0;


// define all objects and variables for the LEDs
int brightness = 20;

const int numPins = 10;
byte pinList[numPins] = {24, 15, 16, 17, 18, 19, 20, 21, 22, 23};
const int ledsPerStrip = 100;
CRGB pixels[numPins * ledsPerStrip];
DMAMEM int displayMemory[ledsPerStrip * numPins * 3 / 4];
int drawingMemory[ledsPerStrip * numPins * 3 / 4];
OctoWS2811 octo(ledsPerStrip, displayMemory, drawingMemory, WS2811_GRB | WS2811_800kHz, numPins, pinList);
CTeensy4Controller<GRB, WS2811_800kHz> *pcontroller;



// define all objects and variables for the SD card

File root;





// define all objects and variables for the RTC
time_t getTeensy3Time() {
	return Teensy3Clock.get();
}




//define all objects and variables for the USB Host
JoystickData joystickData[4];






void setup(void) {

  // initialize the LCD
  tft.init();
  tft.setRotation(3);
  tft.fillScreen(TFT_BLACK);
  tft.setCursor(0, 0);

  tft.setCursor(0, 0);
  tft.setTextColor(TFT_WHITE, TFT_BLACK);
  tft.setTextDatum(MC_DATUM);
  tft.setTextSize(4);
  tft.drawString("Initializing...", tft.width() / 2, 80);

  tft.setTextSize(2);
  int textWidth = tft.drawString("I/O...", tft.width() / 2, 140);
  delay(initDelay);

  analogWriteFrequency(LEFT_FAN, 20000);

  pinMode(BUTTON, INPUT_PULLUP);
  pinMode(LEFT_FAN, OUTPUT);
  pinMode(RIGHT_FAN, OUTPUT);
  pinMode(BUTTON_LIGHT, OUTPUT);
  digitalWrite(BUTTON_LIGHT, HIGH);
  pinMode(channel1, INPUT);
  pinMode(channel2, INPUT);
  pinMode(mic, INPUT);
  pinMode(SD_CS, OUTPUT);
  digitalWrite(SD_CS, HIGH);
  randomSeed(analogRead(4));
  attachInterrupt(digitalPinToInterrupt(BUTTON), resetTeensy, FALLING);
  Entropy.Initialize();

  tft.drawString("Ok", textWidth/2 + tft.width() / 2, 140);
  delay(initDelay);


  textWidth = tft.drawString("Serial...", tft.width() / 2, 170);
  delay(initDelay);
  
  Serial.begin(115200);
  Serial1.begin(115200);

  tft.drawString("Ok", textWidth/2 + tft.width() / 2, 170);
  delay(initDelay);


  textWidth = tft.drawString("SD Card...", tft.width() / 2, 200);
  delay(initDelay);

  if (!SD.begin(SPI_QUARTER_SPEED, SD_CS)) {
    tft.setTextColor(TFT_RED, TFT_BLACK);
    tft.drawString("Error", textWidth + tft.width() / 2, 200);
    //while (true) {}
    
  } else {
    tft.drawString("Ok", textWidth/2 + tft.width() / 2, 200);
    delay(initDelay);
  }


  textWidth = tft.drawString("USB Host...", tft.width() / 2, 230);
  delay(initDelay);

  myusb.begin();

  tft.drawString("Ok", textWidth/2 + tft.width() / 2, 230);
  delay(initDelay);




  textWidth = tft.drawString("LEDs...", tft.width() / 2, 260);
  delay(initDelay);

  octo.begin();
  pcontroller = new CTeensy4Controller<GRB, WS2811_800kHz>(&octo);

  FastLED.setBrightness(brightness);
  FastLED.addLeds(pcontroller, pixels, numPins * ledsPerStrip).setCorrection(TypicalLEDStrip);

  tft.drawString("Ok", textWidth/2 + tft.width() / 2, 260);
  delay(initDelay);


  textWidth = tft.drawString("RTC...", tft.width() / 2, 290);
  delay(initDelay);

  setSyncProvider(getTeensy3Time);
  timeStatus();

  tft.drawString("Ok", textWidth/2 + tft.width() / 2, 290);
  delay(initDelay);



  analogWrite(LEFT_FAN , 255);
  analogWrite(RIGHT_FAN, 255);


  tft.setCursor(0, 0);
  tft.fillScreen(TFT_BLACK);
  tft.setTextColor(TFT_GREEN, TFT_BLACK);
  tft.setTextDatum(MC_DATUM);
  tft.setTextSize(4);
  tft.drawString("Tesseract Ready!", tft.width() / 2, 100);
  tft.drawRect(19, 129, tft.width() - 28, 22, TFT_WHITE);
  tft.fillRect(20, 130, tft.width() - 38, 20, TFT_BLACK);

  for (int i = 0; i < tft.width() - 40; i++)
  {
    tft.fillRect(20, 130, i, 20, TFT_GREEN);
    delay(initDelay*3 / (tft.width() - 40));
  }
  delay(initDelay);

  tft.fillScreen(TFT_BLACK);
}








void loop() {

  handleUsb();

  temp = InternalTemperature.readTemperatureC();
  setFanSpeed(temp);
  FastLED.clear(true);
  
  


startMenu:

  touchX = 0;
  touchY = 0;
  int effectType = 0;
  int effect = 0;
    //  1 - Normal Effects
    //  2 - Sound Reactive Effects
    //  3 - Games

  nextMenu = mainMenu(tft);
  effectType = nextMenu;

  if (nextMenu == 1 || nextMenu == 2 || nextMenu == 3 || nextMenu == 4)
  {
    effect = effectsMenu(tft, nextMenu);

    if (effect == 0)
    {
      goto startMenu;
    
    } else 
    {
      startEffect(effectType, effect);
    }
    
  } else if (nextMenu == 5)
  {
    debugMenu(tft, pixels, temp, fps);
  } else if (nextMenu == 6)
  {
    presentation(pixels, tft);
  }





  if (digitalRead(BUTTON) == LOW) {
    digitalWrite(BUTTON_LIGHT, HIGH);
  } else {
    digitalWrite(BUTTON_LIGHT, LOW);
  }


}


















extern int touchX, touchY;


void startEffect(int effectType, int effect)
{

  if (effectType == 1) // Normal Effects
  {
    tft.fillScreen(TFT_BLACK);
    tft.setCursor(0, 0);
    tft.setTextColor(TFT_WHITE);
    tft.setTextSize(2);
    int rectX = 40;
    int rectY = 40;
    int rectWidth = 80;
    int rectHeight = 80;
    

    tft.fillRect(rectX, rectY, rectWidth, rectHeight, TFT_RED);
    // Center a smaller rectangle inside the larger rectangle
    tft.fillRect(rectX + (rectWidth - rectWidth * 0.4) / 2, rectY + (rectHeight - rectHeight * 0.4) / 2, rectWidth * 0.4, rectHeight * 0.4, TFT_WHITE);

    int hue = 0;

    delay(200);

  playEffect:

    touchX = 0;
    touchY = 0;

    while (touchX == 0 || touchY == 0)
    {
        checkTouch(tft);

        if (effect == 1)
        {
            simpleRainbow(pixels, 1, 20);
        } else if (effect == 2)
        {
            fillCube(pixels, CHSV(hue, 255, 255));
            FastLED.show();
            hue++;

        } else if (effect == 3)
        {
            drawText(pixels, "TESSERACT", 0, 40, 80);
            hue += 15;
        } else if (effect == 4)
        {
            FastLED.setBrightness(160);
            lines(pixels);
        } else if (effect == 5)
        {
            sparkles(pixels, 10, false, 10);
        } else if (effect == 6)
        {
            sparkles(pixels, 10, true, 10);
        } else if (effect == 7)
        {
            planets(pixels, 12);
        } else if (effect == 8)
        {
            FastLED.setBrightness(120);
            vortex(pixels, 6);
        } else if (effect == 9)
        {
            tesseract(pixels, 100);
        } else if (effect == 10) {
            clock(pixels, 100);
        }


        if (touchX > rectX && touchX < rectX + rectWidth && touchY > rectY && touchY < rectY + rectHeight)
        { 
          break;
        }
        else
        { 
          goto playEffect;
        }
    }



  } else if (effectType == 2) // Sound Reactive Effects
  {
    tft.fillScreen(TFT_BLACK);
    tft.setCursor(0, 0);
    tft.setTextColor(TFT_WHITE);
    tft.setTextSize(2);
    int rectX = 40;
    int rectY = 40;
    int rectWidth = 80;
    int rectHeight = 80;

    
    int tempBrightness = FastLED.getBrightness();
    int tempTouchX = map(tempBrightness, 0, 255, 20, tft.width() - 20);

    tft.fillRect(rectX, rectY, rectWidth, rectHeight, TFT_RED);
    tft.fillRect(rectX + (rectWidth - rectWidth * 0.4) / 2, rectY + (rectHeight - rectHeight * 0.4) / 2, rectWidth * 0.4, rectHeight * 0.4, TFT_WHITE);

    tft.drawRect(19, 179, tft.width() - 28, 22, TFT_WHITE);
    tft.fillRect(20, 180, tft.width() - 20 - 2 - 20, 20, TFT_BLACK);
    tft.fillRect(20, 180, max(1, tempTouchX - 10), 20, 0x2786ba);
    tft.fillRoundRect(tempTouchX, 175, 12, 30, 3, TFT_ORANGE);


    delay(200);

    setupFFT();

playSoundEffect:

    touchX = 0;
    touchY = 0;


    while (touchX == 0 || touchY == 0)
    {
        checkTouch(tft);

        if (touchX > 20 && touchX < tft.width() - 20 && touchY > 160 && touchY < 220)
        {
          if (touchX != tempTouchX)
          {
            tempTouchX = touchX;
            tempBrightness = map(touchX, 20, tft.width() - 20, 0, 255);
            FastLED.setBrightness(tempBrightness);
            tft.fillRect(20, 175, tft.width() - 20 - 2, 4, TFT_BLACK);
            tft.fillRect(20, 201, tft.width() - 20 - 2, 4, TFT_BLACK);
            tft.drawRect(19, 179, tft.width() - 28, 22, TFT_WHITE);
            tft.fillRect(20, 180, tft.width() - 20 - 2, 20, TFT_BLACK);

            tft.fillRect(20, 180, max(1, touchX - 10), 20, 0x2786ba);
            tft.fillRoundRect(touchX, 175, 12, 30, 3, TFT_ORANGE);
          }
        }

        
        if (effect == 1)
        {
          setFanSpeed(0);
          spectrumAnalyser(pixels, mic);
        } else if (effect == 2)
        {
          //spectrumAnalyser(layers, channel1);
        } else if (effect == 3)
        {

        } else if (effect == 4)
        {

        }

        if (touchX > rectX && touchX < rectX + rectWidth && touchY > rectY && touchY < rectY + rectHeight)
        { 
          break;
        }
        else
        { 
          goto playSoundEffect;
        }
    }

  } else if (effectType == 3) // Games
  {
    tft.fillScreen(TFT_BLACK);
    tft.setCursor(0, 0);
    tft.setTextColor(TFT_WHITE);
    tft.setTextSize(2);
    int rectX = 40;
    int rectY = 40;
    int rectWidth = 80;
    int rectHeight = 80;

    tft.fillRect(rectX, rectY, rectWidth, rectHeight, TFT_RED);
    tft.fillRect(rectX + (rectWidth - rectWidth * 0.4) / 2, rectY + (rectHeight - rectHeight * 0.4) / 2, rectWidth * 0.4, rectHeight * 0.4, TFT_WHITE);

    int hue = 0;

    delay(200);

  playGame:

    touchX = 0;
    touchY = 0;

    while (touchX == 0 || touchY == 0)
    {
      checkTouch(tft);

      if (effect == 1)
      {
          playTetris(pixels, tft, 6, 10);

      } else if (effect == 2)
      {
          //fillCube(layers, CHSV(hue, 255, 255));
          FastLED.show();
          hue += 3;
      } else if (effect == 3)
      {
          //drawText(layers, "TESSERACT", 0, 40, 10);
          hue += 15;
      } else if (effect == 4)
      {
          //bouncingBall(layers, 0, 15, 100, 100);
      }
      if (touchX > rectX && touchX < rectX + rectWidth && touchY > rectY && touchY < rectY + rectHeight)
      { 
        break;
      }
      else
      { 
        goto playGame;
      }
    }

  }
    
    //clear the cube
    fillCube(pixels, CHSV(0, 0, 0));
    FastLED.setBrightness(brightness);
    FastLED.show();

}

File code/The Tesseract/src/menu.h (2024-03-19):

/**
 * @file menu.h
 * @brief Header file for the menu.
 * 
 * Contains the menu functions and variables.
 */


#ifndef MENU_H
#define MENU_H

#include <Arduino.h>
#include <SPI.h>
#include <Wire.h>
#include <TFT_eSPI.h>
#define FastLED_INTERNAL
#include <FastLED.h>
#include "tesseractFunctions.h"
#include "effects/effects.h"
#include "images.h"

#define NUM_LEDS 1000
#define NUM_LAYERS 10

extern float temp;
double fps;
double timeStart;
double timeEnd;

//define a array for the names of the effects
const char *normalEffects[11] = {"Rainbow", "Cube Fill", "Flying Text", "Lines", "Sparkles", "Sparkles - RGB", "Planets", "Vortex", "Tesseract", "Clock", "Coming soon"};
const char *soundReactiveEffects[4] = {"VU Meter", "Coming soon", "Coming soon", "Coming soon"};
const char *games[4] = {"Tetris", "Coming soon", "Coming soon", "Coming soon"};
const char *omnitouchEffects[4] = {"Rotation", "Magnet", "Temperature", "Mode"};
int touchX, touchY;

void drawMenu(TFT_eSPI tft, int menuIndex);
int mainMenu(TFT_eSPI tft);
int effectsMenu(TFT_eSPI tft);
void settingsMenu(TFT_eSPI tft);
void debugMenu(TFT_eSPI tft, CRGB pixels[NUM_LEDS], float temp, double fps);
void checkTouch(TFT_eSPI tft);


void drawMenu(TFT_eSPI tft, int menuIndex)
{
    if (menuIndex == 0)
    {
        mainMenu(tft);
    }
    else if (menuIndex == 1)
    {
        effectsMenu(tft);
    }
    else if (menuIndex == 2)
    {
        settingsMenu(tft);
    }
    else if (menuIndex == 3)
    {
        debugMenu(tft, pixels, temp, fps);
    }
}



int mainMenu(TFT_eSPI tft)
{
    tft.fillScreen(TFT_BLACK);
    tft.setCursor(0, 0);
    tft.setTextColor(TFT_WHITE);
    tft.setTextSize(2);
    int buttonX = 40;
    int buttonY = 30;
    int buttonWidth = 80;
    int buttonHeight = 80;

    int button2X = buttonX + buttonWidth + 30;
    int button3X = button2X + buttonWidth + 30;
    int button4X = button3X + buttonWidth + 30;

    int debuxX = 400;
    int debugY = 240;
    int debugWidth = 60;
    int debugHeight = 60;

    int presentationX = 20;
    int presentationY = 240;
    int presentationWidth = 60;
    int presentationHeight = 60;


    tft.fillRect(buttonX, buttonY, buttonWidth, buttonHeight, TFT_GREEN);
    tft.pushImage(buttonX + 10, buttonY + 10, 60, 60, stars_icon);

    tft.fillRect(button2X, buttonY, buttonWidth, buttonHeight, TFT_PINK);
    tft.pushImage(button2X + 10, buttonY + 10, 60, 60, note_icon);

    tft.fillRect(button3X, buttonY, buttonWidth, buttonHeight, TFT_YELLOW);
    tft.pushImage(button3X + 10, buttonY + 10, 60, 60, gamepad_icon);

    tft.fillRect(button4X, buttonY, buttonWidth, buttonHeight, TFT_BLUE);
    tft.pushImage(button4X + 10, buttonY + 10, 60, 60, omnitouch_icon);

    tft.fillRect(debuxX, debugY, debugWidth, debugHeight, TFT_LIGHTGREY);
    tft.pushImage(debuxX + 5, debugY + 5, 50, 50, debug_icon);

    tft.fillRect(presentationX, presentationY, presentationWidth, presentationHeight, TFT_CYAN);
    tft.pushImage(presentationX + 5, presentationY + 5, 50, 50, presentation_icon);

    delay(200);

    touchX = 0;
    touchY = 0;

waitForTouch:

    while (touchX == 0 || touchY == 0)
    {
        checkTouch(tft);
    }

    //check if the user has touched the screen and if the user has touched the button if not, then do nothing
    if (touchX > buttonX && touchX < buttonX + buttonWidth && touchY > buttonY && touchY < buttonY + buttonHeight)
    {
        touchX = 0;
        touchY = 0;
        return 1;
    }
    else if (touchX > button2X && touchX < button2X + buttonWidth && touchY > buttonY && touchY < buttonY + buttonHeight)
    {
        touchX = 0;
        touchY = 0;
        return 2;
    }
    else if (touchX > button3X && touchX < button3X + buttonWidth && touchY > buttonY && touchY < buttonY + buttonHeight)
    {
        touchX = 0;
        touchY = 0;
        return 3;
    }
    else if (touchX > button4X && touchX < button4X + buttonWidth && touchY > buttonY && touchY < buttonY + buttonHeight)
    {
        touchX = 0;
        touchY = 0;
        return 4;
    }
    else if (touchX > debuxX && touchX < debuxX + debugWidth && touchY > debugY && touchY < debugY + debugHeight)
    {
        touchX = 0;
        touchY = 0;
        return 5;
    }
    else if (touchX > presentationX && touchX < presentationX + presentationWidth && touchY > presentationY && touchY < presentationY + presentationHeight)
    {
        touchX = 0;
        touchY = 0;
        return 6;
    }
    else
    {
        touchX = 0;
        touchY = 0;
        goto waitForTouch;
    }
}



int effectsMenu(TFT_eSPI tft, int effectType)
{
    const char **effects = nullptr;
    if (effectType == 1)
    {
        effects = normalEffects;
    }
    else if (effectType == 2)
    {
        effects = soundReactiveEffects;
    }
    else if (effectType == 3)
    {
        effects = games;
    }
    else if (effectType == 4)
    {
        effects = omnitouchEffects;
    }
    else
    {
        return 0;
    }

    int effectIndex = 0;

    //draw the effects menu on the tft screen with each effect in a button in a wide rectangle with the effect name in the middle of the rectangle 
    //and two buttons on the top and bottom of the screen for scrolling through the effects menu
    //and a button on the top right corner of the screen for going back to the main menu

    tft.fillScreen(TFT_BLACK);
    tft.setCursor(0, 0);
    tft.setTextColor(TFT_WHITE);
    tft.setTextDatum(MC_DATUM);
    tft.setTextSize(2);

    int effectButtonX = 40;
    int effectButtonY = 30;
    int effectButtonW = 200;
    int effectButtonH = 50;
    int upButtonX = 280;
    int upButtonY = 30;
    int upButtonW = 60;
    int upButtonH = 60;
    int downButtonX = 280;
    int downButtonY = 230;
    int downButtonW = 60;
    int downButtonH = 60;
    int backButtonX = 380;
    int backButtonY = 30;
    int backButtonW = 60;
    int backButtonH = 60;

    //draw the buttons for scrolling through the effects menu as squares with arrows in them on the top and bottom of the screen
    tft.fillRect(upButtonX, upButtonY, upButtonW, upButtonH, TFT_RED);
    tft.fillTriangle(upButtonX + upButtonW / 4, upButtonY + upButtonH * 3 / 4, upButtonX + upButtonW * 3 / 4, upButtonY + upButtonH * 3 / 4, upButtonX + upButtonW / 2, upButtonY + upButtonH / 4, TFT_WHITE);

    tft.fillRect(downButtonX, downButtonY, downButtonW, downButtonH, TFT_RED);
    tft.fillTriangle(downButtonX + downButtonW / 4, downButtonY + downButtonH / 4, downButtonX + downButtonW * 3 / 4, downButtonY + downButtonH / 4, downButtonX + downButtonW / 2, downButtonY + downButtonH * 3 / 4, TFT_WHITE);


    //draw the button for going back to the main menu as a square with an arrow in it on the top right corner of the screen
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

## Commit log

2024-03-19 Added the CAD, PCB files and Documentation
    [10x10 Jig.3mf, 1x1 Jig.3mf, 1x1 Jig.f3d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]
2024-12-29 working on readme
    [Drill_NPTH_Through.DRL, Drill_PTH_Through.DRL, Gerber_BottomLayer.GBL]
